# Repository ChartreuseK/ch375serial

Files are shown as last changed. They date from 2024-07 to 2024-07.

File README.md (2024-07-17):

# CH375 to RS-232 Adapter

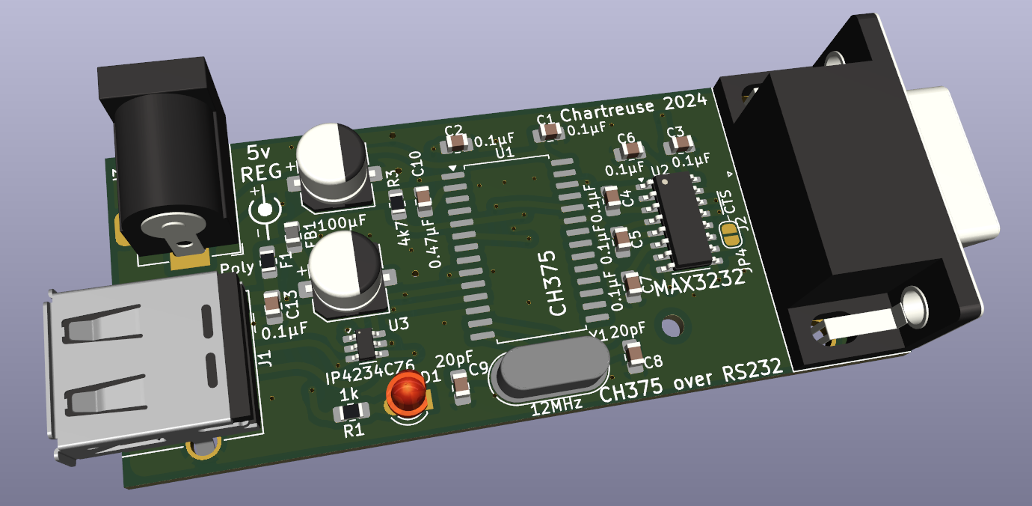
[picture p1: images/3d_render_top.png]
3D Render of PCB


This adapter is designed to allow usb mass storage media to be accessible to a computer over standard RS232. As such it contains a CH375 to do the heavy lifting along with a MAX3232 rs-232 level shifter to drive full serial levels. An external regulated 5v source is required to power the device as well as any attached USB storage devices. This could be provided by a USB to barrel jack adapter with a cell phone charger, a stand alone switching wall supply, or possibly even by a ps/2 keyboard port tap that borrows some power from such a port.

This is still in the testing stage and has not yet been constructed, however the circuitry is heavilly based on the original datasheet examples so likely will work.

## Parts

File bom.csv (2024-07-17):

Reference | Value | Datasheet | Footprint | Qty | DNP | LCSC
C1,C2,C3,C4,C5,C6,C7,C13 | 0.1µF | ~ | Capacitor_SMD:C_0805_2012Metric_Pad1.18x1.45mm_HandSolder | 8 |  | C49678
C8,C9 | 20pF | ~ | Capacitor_SMD:C_0805_2012Metric_Pad1.18x1.45mm_HandSolder | 2 |  | C1798
C10 | 0.47µF | ~ | Capacitor_SMD:C_0805_2012Metric_Pad1.18x1.45mm_HandSolder | 1 |  | C13967
C11,C12 | 100µF 16v | ~ | Capacitor_SMD:CP_Elec_6.3x5.9 | 2 |  | C340733
FB1 | FerriteBead_Small | ~ | Inductor_SMD:L_0805_2012Metric_Pad1.15x1.40mm_HandSolder | 1 |  | C1015
J1 | USB_A | ~ | Connector_USB:USB_A_Molex_67643_Horizontal | 1 |  | C456018
J2 | DE9_Receptacle_MountingHoles | ~ | Connector_Dsub:DSUB-9_Female_Horizontal_P2.77x2.84mm_EdgePinOffset7.70mm_Housed_MountingHolesOffset9.12mm | 1 |  | C19077337
J3 | Barrel_Jack_MountingPin | ~ | Connector_BarrelJack:BarrelJack_Horizontal | 1 |  | C16214
R1 | 1k | ~ | Resistor_SMD:R_0805_2012Metric_Pad1.20x1.40mm_HandSolder | 1 |  | C17513
R3 | 4k7 | ~ | Resistor_SMD:R_0805_2012Metric_Pad1.20x1.40mm_HandSolder | 1 |  | C17673
U1 | CH375 | https://www.wch-ic.com/downloads/CH375DS1_PDF.html | Package_SO:SOP-28_8.4x18.16mm_P1.27mm | 1 |  | C8962
U2 | MAX3232 | https://datasheets.maximintegrated.com/en/ds/MAX3222-MAX3241.pdf | Package_SO:SOIC-16_3.9x9.9mm_P1.27mm | 1 |  | C193666
U3 | IP4234CZ6 | https://assets.nexperia.com/documents/data-sheet/IP4234CZ6.pdf | Package_TO_SOT_SMD:SC-74-6_1.55x2.9mm_P0.95mm | 1 |  | C355086
Y1 | 12MHz | ~ | Crystal:Crystal_HC49-4H_Vertical | 1 |  | C2857630

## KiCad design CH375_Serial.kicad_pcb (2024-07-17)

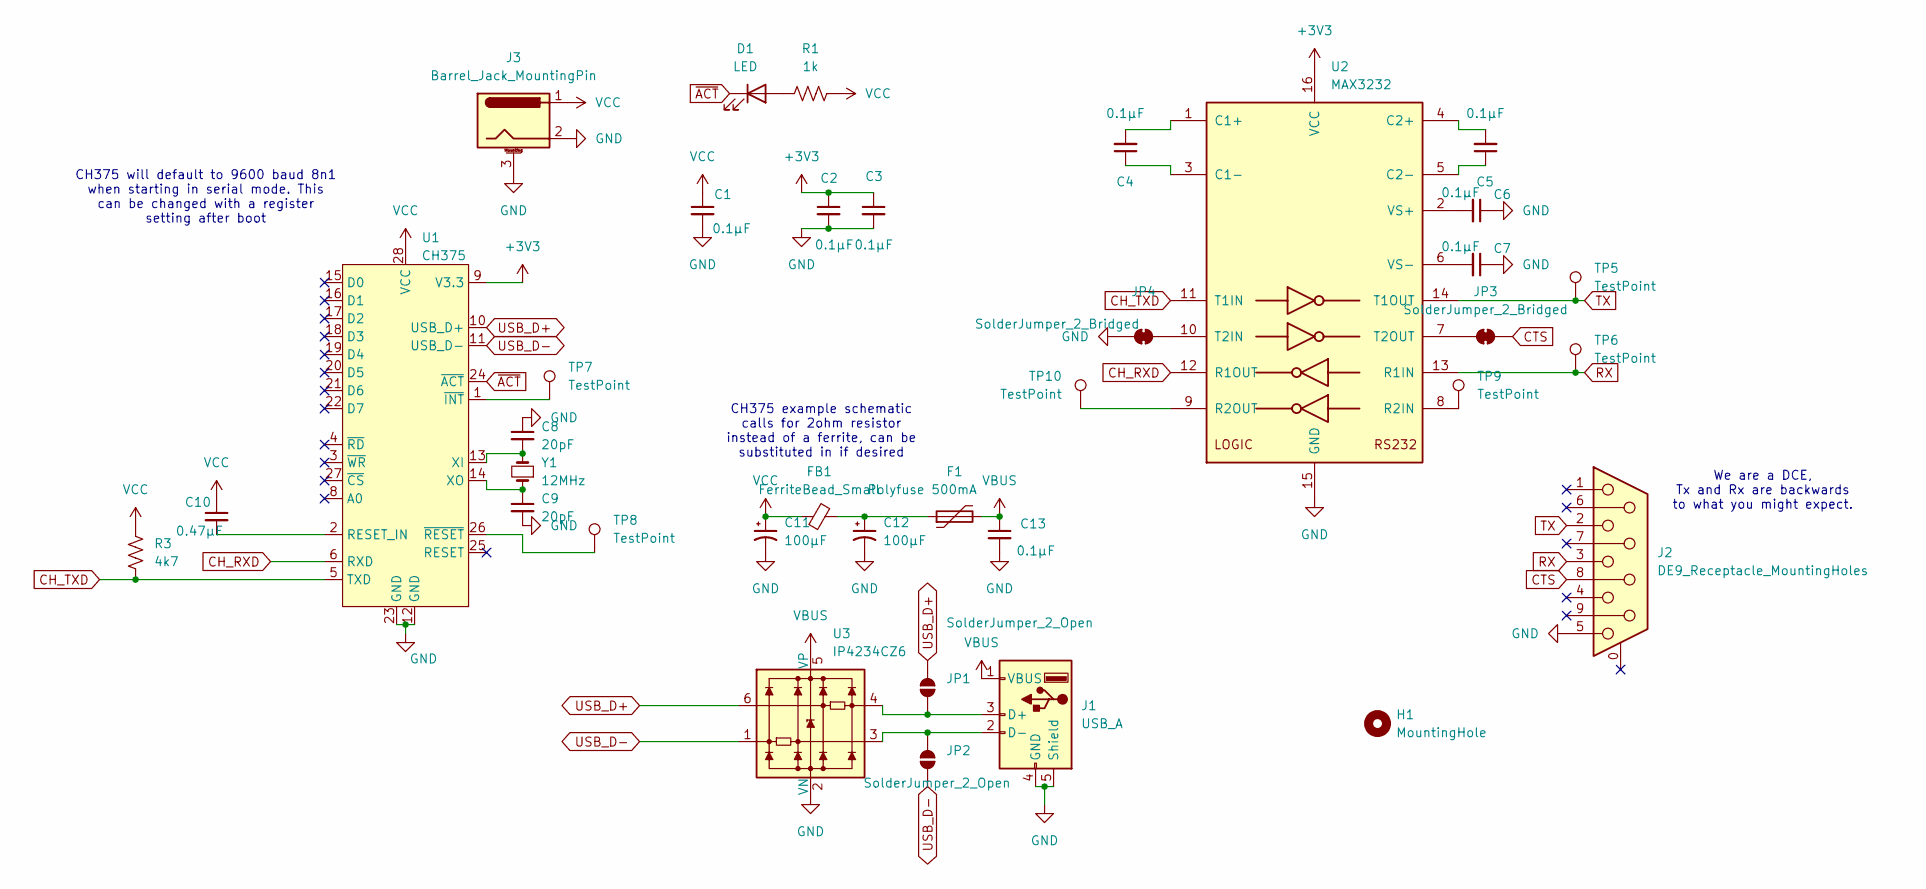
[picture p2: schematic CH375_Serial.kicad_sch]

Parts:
C1, C2, C3, C4, C5, C6, C7, C13: 0.1µF; C_0805_2012Metric_Pad1.18x1.45mm_HandSolder
C8, C9: 20pF; C_0805_2012Metric_Pad1.18x1.45mm_HandSolder
C10: 0.47µF; C_0805_2012Metric_Pad1.18x1.45mm_HandSolder
C11, C12: 100µF; CP_Elec_6.3x5.9
D1: LED; LED_D3.0mm
F1: Polyfuse 500mA; R_0805_2012Metric_Pad1.20x1.40mm_HandSolder
FB1: FerriteBead_Small; L_0805_2012Metric_Pad1.15x1.40mm_HandSolder
H1: MountingHole; MountingHole_2.2mm_M2
J1: USB_A; USB_A_Molex_67643_Horizontal
J2: DE9_Receptacle_MountingHoles; DSUB-9_Female_Horizontal_P2.77x2.84mm_EdgePinOffset7.70mm_H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
J3: Barrel_Jack_MountingPin; BarrelJack_Horizontal
JP1, JP2: SolderJumper_2_Open; SolderJumper-2_P1.3mm_Open_RoundedPad1.0x1.5mm
JP3, JP4: SolderJumper_2_Bridged; SolderJumper-2_P1.3mm_Bridged_RoundedPad1.0x1.5mm
R1: 1k; R_0805_2012Metric_Pad1.20x1.40mm_HandSolder
R3: 4k7; R_0805_2012Metric_Pad1.20x1.40mm_HandSolder
TP5, TP6, TP7, TP8, TP9, TP10: TestPoint; TestPoint_Pad_D1.0mm
U1: CH375; SOP-28_8.4x18.16mm_P1.27mm
U2: MAX3232; SOIC-16_3.9x9.9mm_P1.27mm
U3: IP4234CZ6; SC-74-6_1.55x2.9mm_P0.95mm
Y1: 12MHz; Crystal_HC49-4H_Vertical

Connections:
+3V3: C2.1, C3.1, U1.9 (V3.3), U2.16 (VCC)
CH_RXD: U1.6 (RXD), U2.12 (R1OUT)
CH_TXD: R3.1, U1.5 (TXD), U2.11 (T1IN)
CTS: J2.8, JP3.2 (B)
GND: C1.2, C2.2, C3.2, C6.1, C7.1, C8.1, C9.2, C11.2, C12.2, C13.2, J1.4 (GND), J1.5 (Shield), J2.5, J3.2, J3.3 (MountPin), JP4.1 (A), U1.12 (GND), U1.23 (GND), U2.15 (GND), U3.2 (VN)
unnamed: C12.1, F1.1, FB1.2
unnamed: D1.2 (A), R1.1
unnamed: J1.3 (D+), JP1.1 (A), U3.4
unnamed: J1.2 (D-), JP2.2 (B), U3.3
unnamed: JP3.1 (A), U2.7 (T2OUT)
unnamed: JP4.2 (B), U2.10 (T2IN)
unnamed: C10.2, U1.2 (RESET_IN)
unnamed: C8.2, U1.13 (XI), Y1.2
unnamed: C9.1, U1.14 (XO), Y1.1
unnamed: TP7.1, U1.1 (~INT)
unnamed: TP8.1, U1.26 (~RESET)
unnamed: C4.2, U2.1 (C1+)
unnamed: C4.1, U2.3 (C1-)
unnamed: C5.2, U2.4 (C2+)
unnamed: C5.1, U2.5 (C2-)
unnamed: TP9.1, U2.8 (R2IN)
unnamed: TP10.1, U2.9 (R2OUT)
unnamed: C6.2, U2.2 (VS+)
unnamed: C7.2, U2.6 (VS-)
RX: J2.3, TP6.1, U2.13 (R1IN)
TX: J2.2, TP5.1, U2.14 (T1OUT)
USB_D+: JP1.2 (B), U1.10 (USB_D+), U3.6
USB_D-: JP2.1 (A), U1.11 (USB_D-), U3.1
VBUS: C13.1, F1.2, J1.1 (VBUS), U3.5 (VP)
VCC: C1.1, C10.1, C11.1, FB1.1, J3.1, R1.2, R3.2, U1.28 (VCC)
~ACT: D1.1 (K), U1.24 (~ACT)

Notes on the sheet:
CH375 example schematic calls for 2ohm resistor instead of a ferrite, can be substituted in if desired
CH375 will default to 9600 baud 8n1 when starting in serial mode. This can be changed with a register setting after boot
We are a DCE, Tx and Rx are backwards to what you might expect.

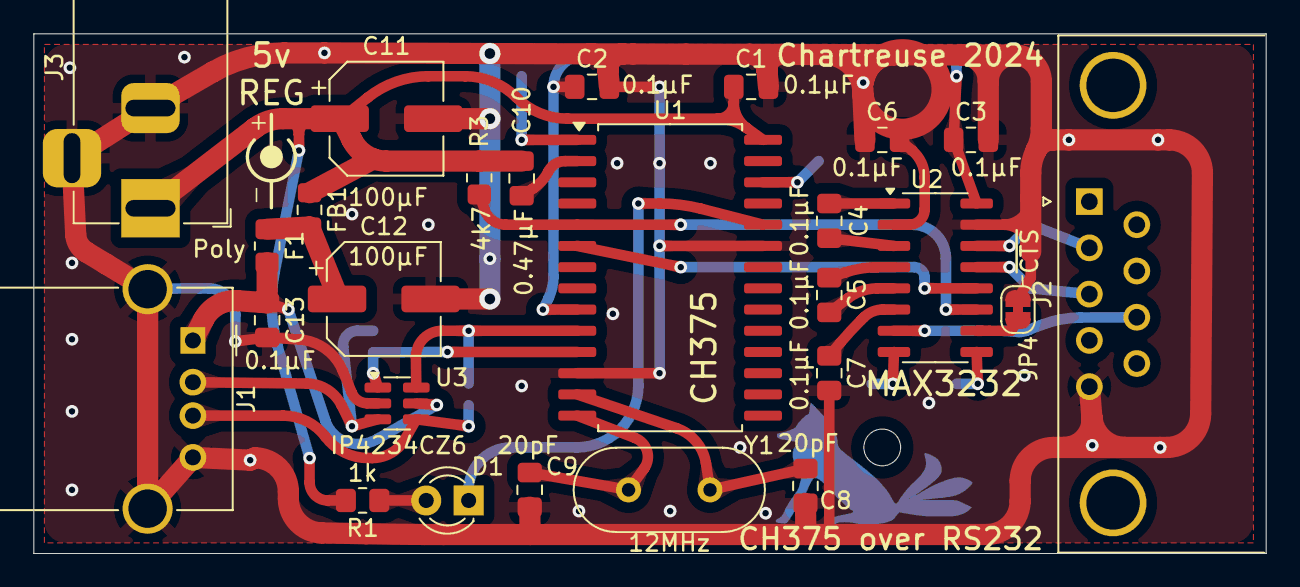
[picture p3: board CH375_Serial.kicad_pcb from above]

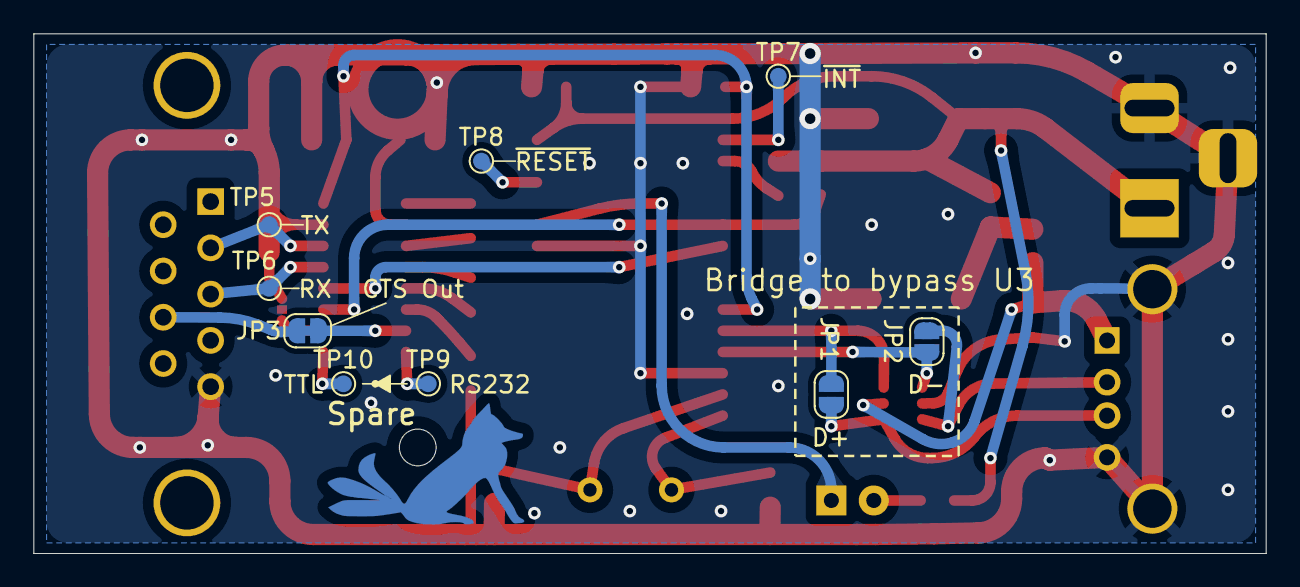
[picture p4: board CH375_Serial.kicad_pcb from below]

Board: 2 copper layers, 73.8 x 31.1 mm, 36 parts (9 on the bottom side), 31 nets.

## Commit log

2024-07-17 Initial version of CH375 adapter.
    [CH375_Serial-B_Cu.gbl, CH375_Serial-B_Mask.gbs, CH375_Serial-B_Paste.gbp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]
2024-07-17 Added LCSC part numbers for most, exported simple BOM
    [CH375_Serial.kicad_sch, bom.csv]
